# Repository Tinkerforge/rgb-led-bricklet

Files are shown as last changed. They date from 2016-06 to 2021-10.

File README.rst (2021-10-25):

RGB LED Bricklet
================

This repository contains the firmware source code and the hardware design
files. The documentation generator configs can be found at
https://github.com/Tinkerforge/generators

Repository Content
------------------

software/:
 * examples/: Examples for all supported languages
 * build/: Compiled files
 * src/: Source code of firmware
 * Makefile: Makefile to build project

hardware/:
 * Contains KiCad project files and additionally schematics as PDF

datasheets/:
 * Contains datasheets for sensors and complex ICs that are used

Hardware
--------

The hardware is designed with the open source EDA Suite KiCad
(http://www.kicad.org). Before you are able to open the files,
you have to install the Tinkerforge kicad-libraries
(https://github.com/Tinkerforge/kicad-libraries). You can either clone
them directly in hardware/ or clone them in a separate folder and
symlink them into hardware/
(ln -s kicad_path/kicad-libraries project_path/hardware). After that you
can open the .pro file in hardware/ with KiCad and from there view and
modify the schematics and the PCB layout.

Software
--------

If you want to do your own Brick/Bricklet firmware development we highly
recommend that you use our build environment setup script and read the
tutorial (https://www.tinkerforge.com/en/doc/Tutorials/Tutorial_Build_Environment/Tutorial.html).

To compile the C code we recommend you to install the newest GNU Arm Embedded
Toolchain (https://launchpad.net/gcc-arm-embedded/+download).
You also need to install bricklib (https://github.com/Tinkerforge/bricklib)
and brickletlib (https://github.com/Tinkerforge/brickletlib).

You can either clone it directly in software/src/ or clone it in a
separate folder and symlink it into software/src/
(ln -s bricklib_path/bricklib project_path/software/src/ and
ln -s brickletlib_path/brickletlib project_path/software/src/).
Finally make sure to have CMake installed
(http://www.cmake.org/cmake/resources/software.html).

After that you can build the firmware by invoking make in software/.
The firmware (.bin) can then be found in software/build/ and uploaded
with brickv (click button "Flashing" on start screen).

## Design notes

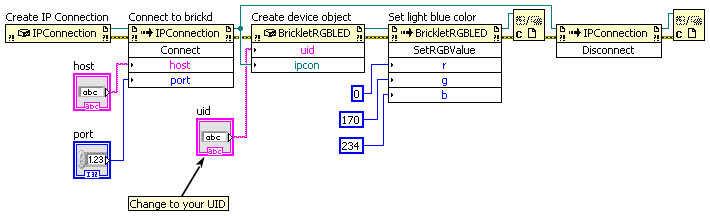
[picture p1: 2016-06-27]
software/examples/labview/Example Simple.vi.png

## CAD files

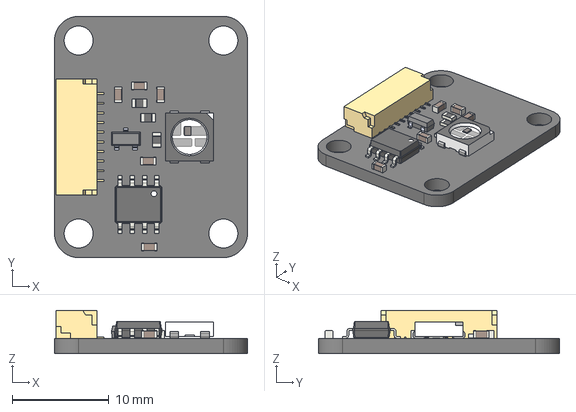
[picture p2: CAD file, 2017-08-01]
hardware/rgb-led.step
20.0 x 25.0 x 4.50 mm

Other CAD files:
hardware/rgb-led.FCStd

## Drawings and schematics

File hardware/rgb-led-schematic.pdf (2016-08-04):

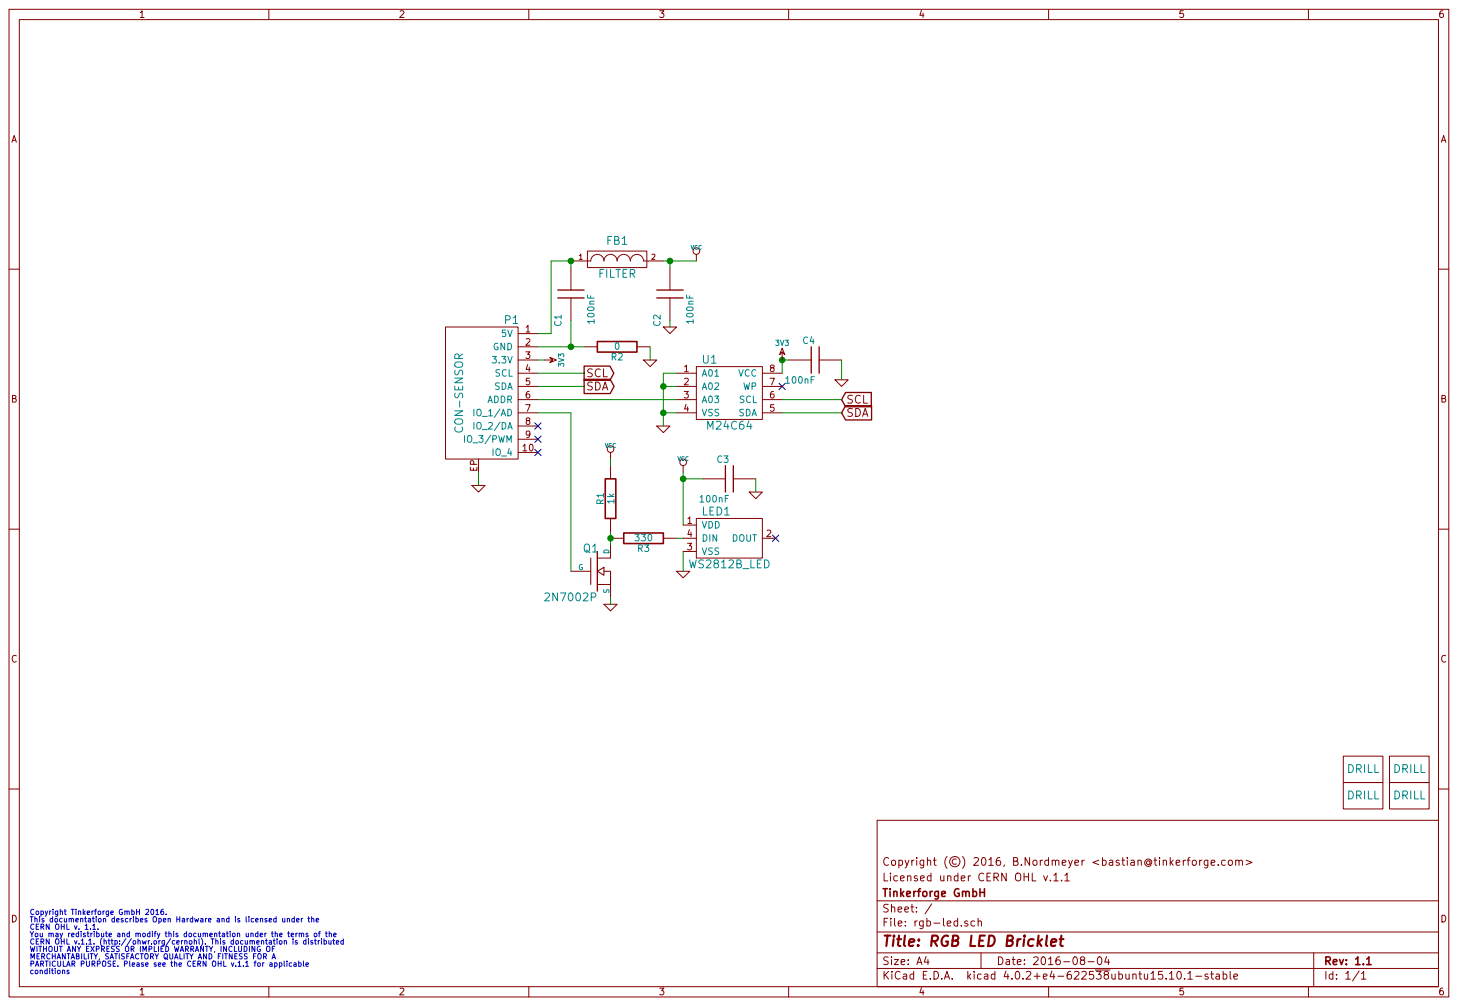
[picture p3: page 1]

Licensed under CERN OHL v.1.1 Copyright (©) 2016, B.Nordmeyer <bastian@tinkerforge.com>

File: rgb-led.sch Sheet: / Tinkerforge GmbH

Copyright Tinkerforge GmbH 2016. This documentation describes Open Hardware and is licensed under the CERN OHL v. 1.1. You may redistribute and modify this documentation under the terms of the CERN OHL v.1.1. (http://ohwr.org/cernohl). This documentation is distributed WITHOUT ANY EXPRESS OR IMPLIED WARRANTY, INCLUDING OF MERCHANTABILITY, SATISFACTORY QUALITY AND FITNESS FOR A

Id: 1/1 Title: RGB LED Bricklet

PARTICULAR PURPOSE. Please see the CERN OHL v.1.1 for applicable

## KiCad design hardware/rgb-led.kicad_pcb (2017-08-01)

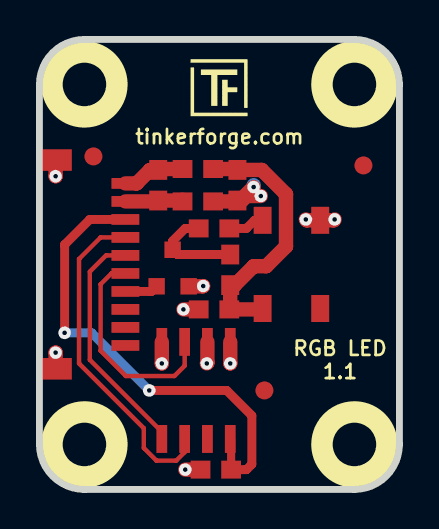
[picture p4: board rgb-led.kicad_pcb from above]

Board: 2 copper layers, 20.0 x 25.0 mm, 20 parts (0 on the bottom side), 11 nets.

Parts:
C1, C2, C3, C4: 100nF; C0603E
FB1: FILTER; C0603E
Fiducial_Mark: VAL**; Fiducial_Mark
Fiducial_Mark#2, Fiducial_Mark#3: VAL**; Fiducial_Mark
LED1: WS2812B_LED
P1: CON-SENSOR
Q1: 2N7002P; SOT23GDS
R1: 1k; R0603E
R2: 0; R0603E
R3: 330; R0603E
U1: M24C64; SOIC8
U2, U3, U4, U5: DRILL; DRILL_NP
VAL: CE_5mm

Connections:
3V3: C4.1, P1.3, U1.8
GND: C2.1, C3.2, C4.2, LED1.3, P1.EP, Q1.S, R2.1, U1.1, U1.2, U1.4
unnamed: C1.1, P1.2, R2.2
unnamed: C1.2, FB1.1, P1.1
unnamed: LED1.4, R3.1
unnamed: P1.6, U1.3
unnamed: P1.7, Q1.G
unnamed: Q1.D, R1.1, R3.2
SCL: P1.4, U1.6
SDA: P1.5, U1.5
VCC: C2.2, C3.1, FB1.2, LED1.1, R1.2

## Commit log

2015-11-18 prototype of rgb pixel bricklet
    [rgb-led.kicad_pcb, rgb-led.sch]
2015-11-23 fully routed, drc check
    [rgb-led.kicad_pcb]
2016-03-31 add fiducials
    [rgb-led.kicad_pcb]
2016-06-10 Add RGB LED Bricklet plugin source
2016-06-10 Fix device identifier
2016-06-17 add schematic
    [rgb-led.sch]
2016-08-04 fix rgb led bricklets dimensions
    [rgb-led.kicad_pcb]
2016-08-04 increase version number to 1.1
    [rgb-led.kicad_pcb, rgb-led.sch]
2016-08-04 update schematic
2016-09-06 Fix green flash after reset
    MOSFET inverts logic, initial pin state needs to be high to ensure low
    output until first frame.
2017-08-01 Fix smybol
    [rgb-led.sch]
2017-08-01 Add 3d information (final)
    [rgb-led.kicad_pcb, rgb-led.sch]
2017-08-01 Add 3d model (*.step & *.FCStd)
    [rgb-led.FCStd, rgb-led.step]
2018-02-20 Cleanup KiCad libraries config
    Ensure LibDir=kicad-libraries and LibName1=tinkerforge.
    Remove special library.
2021-10-25 Update KiCad link
    https://www.kicad.org/blog/2021/10/Avoid-links-to-former-kicad-domain/
